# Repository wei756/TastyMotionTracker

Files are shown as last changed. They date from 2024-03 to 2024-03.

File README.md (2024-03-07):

# TastyMotionTracker
TastyMotionTracker-SlimeVR PCB SMT Project

- Very tiny size
- Using BMI160 6-DoF IMU
- I2C port for additional IMU
- CH340E UART-USB Interface
- Charging Li-Po Battery support

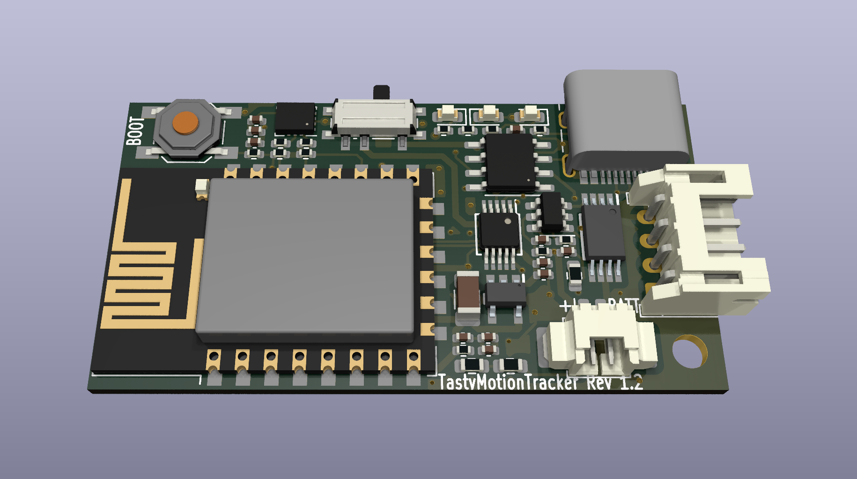
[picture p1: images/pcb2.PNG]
pcb1

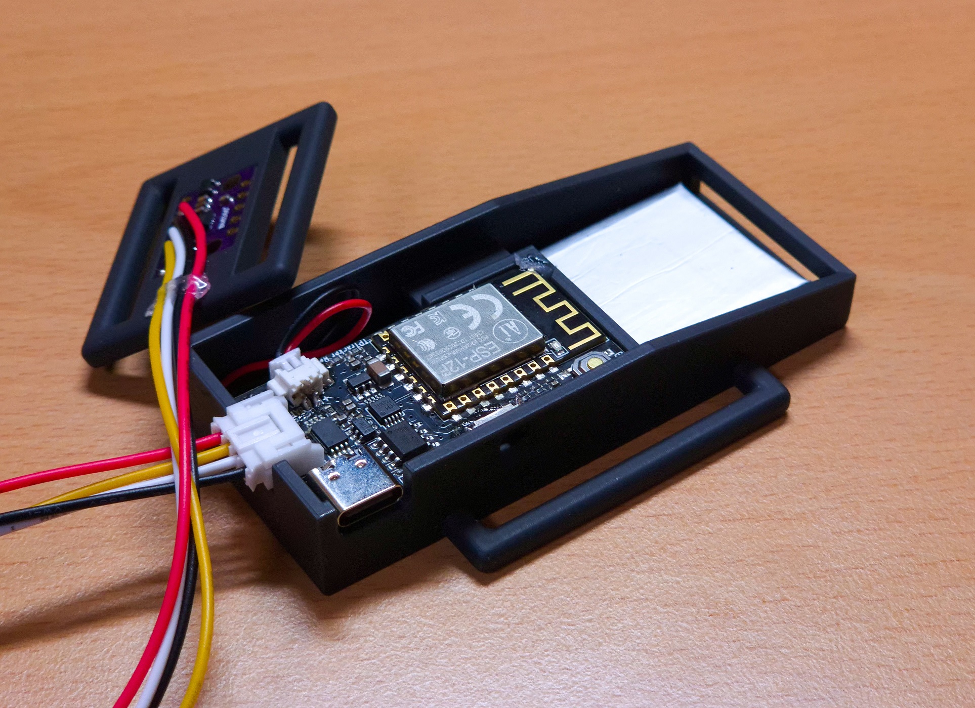
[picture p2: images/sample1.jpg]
sample1


## License
**This hardware is licensed under the CERN-OHL-P v2 license**, which is a permissive,
non-viral and non-reciprocal open hardware license. Unlike software licenses like
MIT and Apache 2.0, it better handles the nuances of hardware and protects both
the licensor and licensee from patent lawsuits.

**Unless you explicitly state otherwise, any contribution intentionally submitted
for inclusion in this work by you, shall be licensed as above, without any
additional terms or conditions.**

### Conveying notice of License
Note that as part of the CERN-OHL-P v2 license, recipients of manufactured
hardware must also receive notice of the above license. One such
method of conveying the notice is to include a link to the original source repo,
or printing "Licensed under CERN-OHL-P v2" on the PCB silkscreen. For more info,
see [here](https://ohwr.org/project/cernohl/wikis/Documents/CERN-OHL-version-2).

This is conceptually similar to the MIT/Apache 2.0 Licenses, where the original
license must still be included as a notice even when the source is modified and
subsequently relicensed under different terms.

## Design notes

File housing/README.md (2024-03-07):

# TastyMotionTracker-Housing

- Using 3.8x27x74mm 800mAh Li-Po Battery

### TODO
- add a cover
- change battery

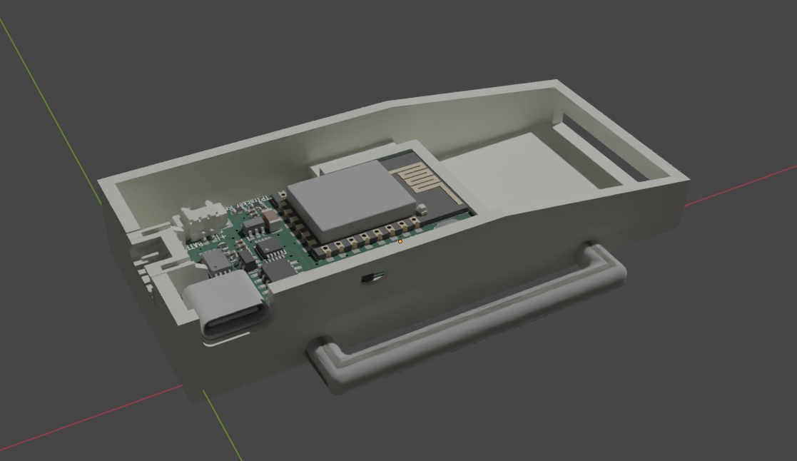
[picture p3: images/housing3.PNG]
housing3

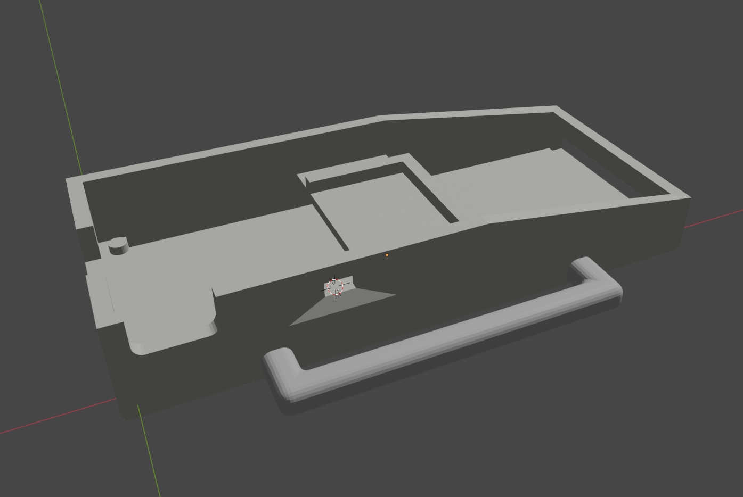
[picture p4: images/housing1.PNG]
housing1

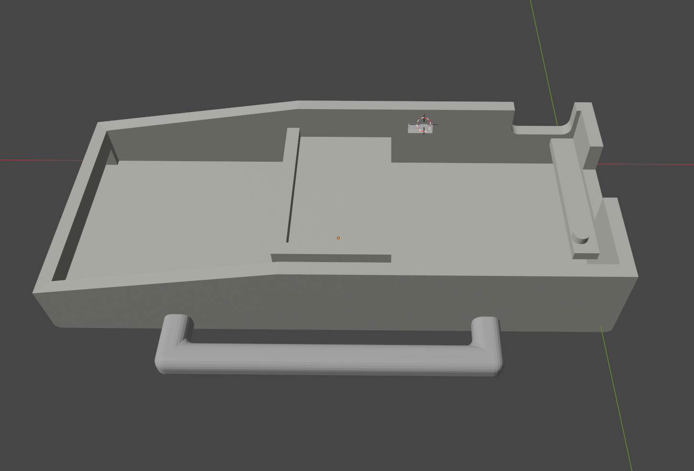
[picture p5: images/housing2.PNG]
housing2


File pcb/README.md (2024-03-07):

# TastyMotionTracker-PCB

### TODO
- fix battery indicator.

pcb2
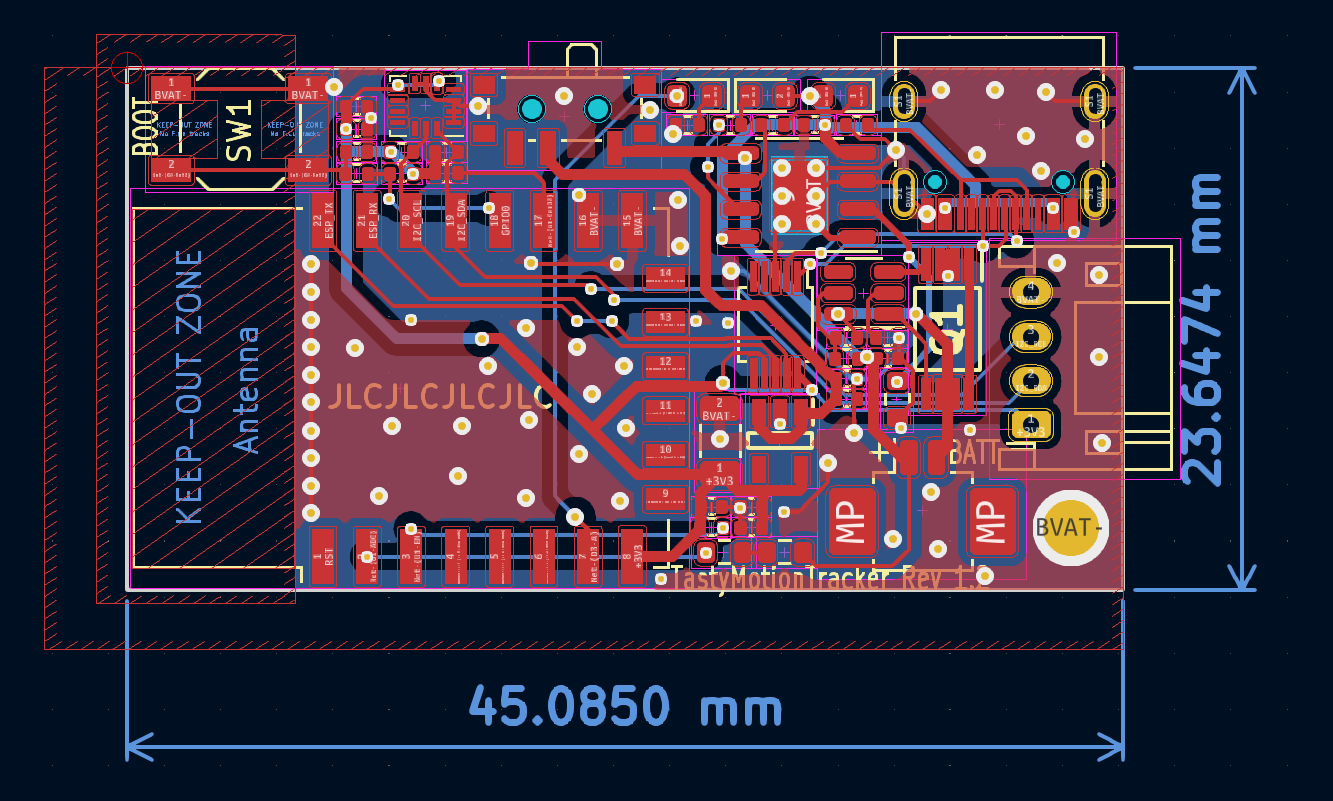
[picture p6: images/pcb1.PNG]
pcb1

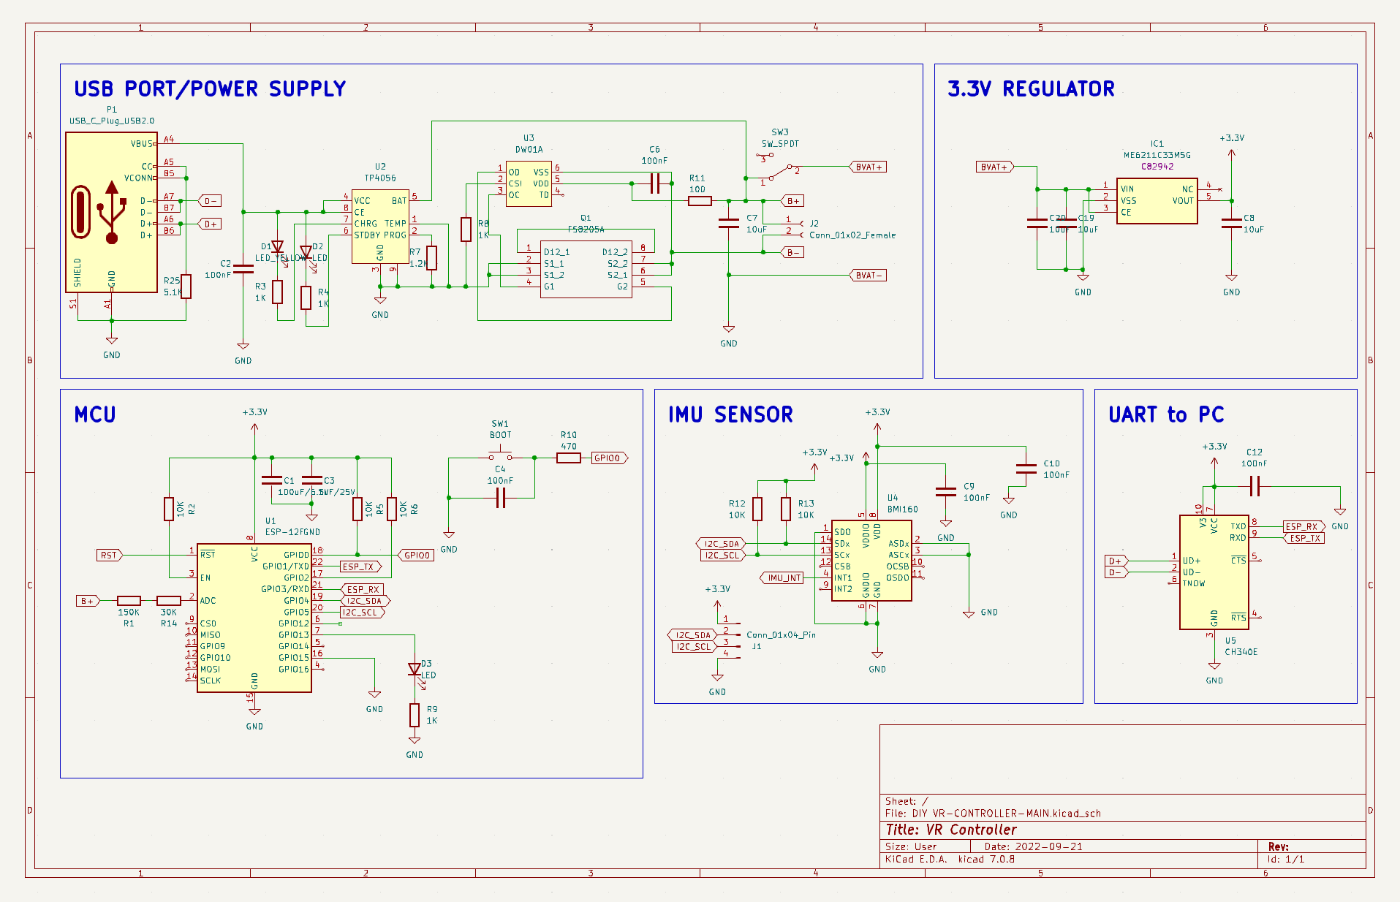
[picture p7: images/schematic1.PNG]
schematic1


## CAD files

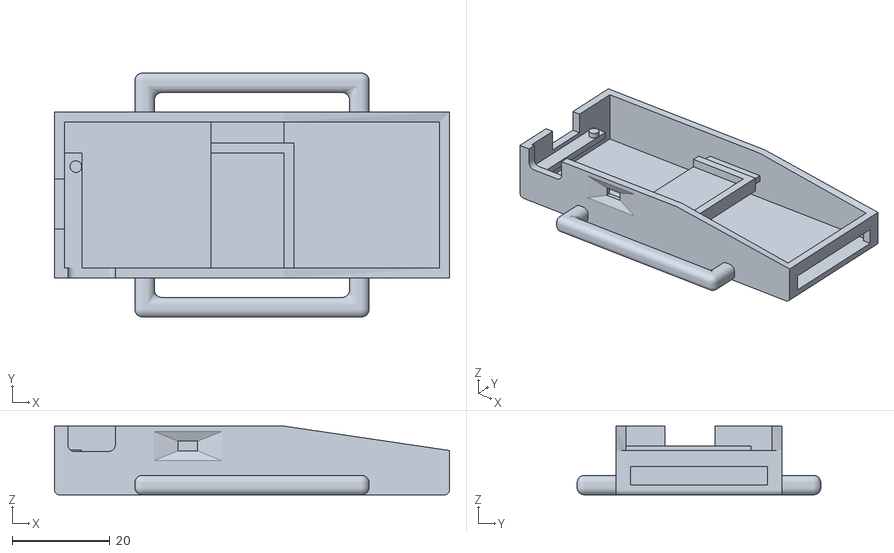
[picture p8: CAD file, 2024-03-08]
housing/TMTracker housing v1.1.stl
81.0 x 50.0 x 14.1

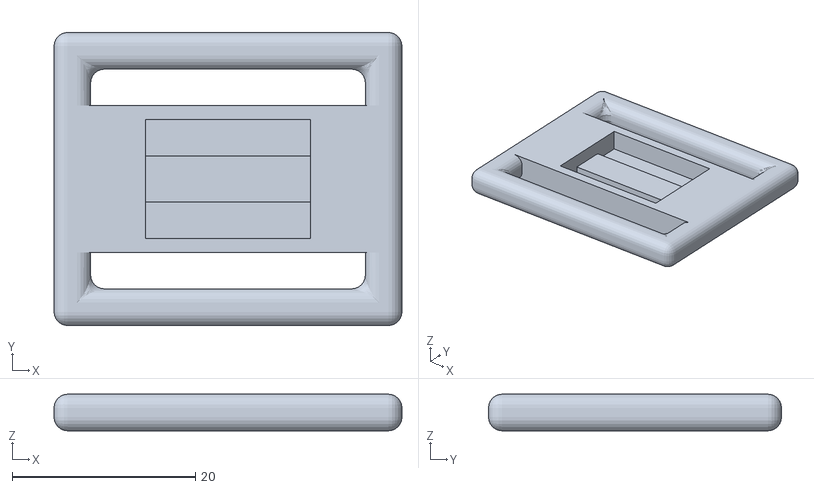
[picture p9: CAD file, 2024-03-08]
housing/TMTracker_ext housing v1.1.stl
38.0 x 32.0 x 4.00

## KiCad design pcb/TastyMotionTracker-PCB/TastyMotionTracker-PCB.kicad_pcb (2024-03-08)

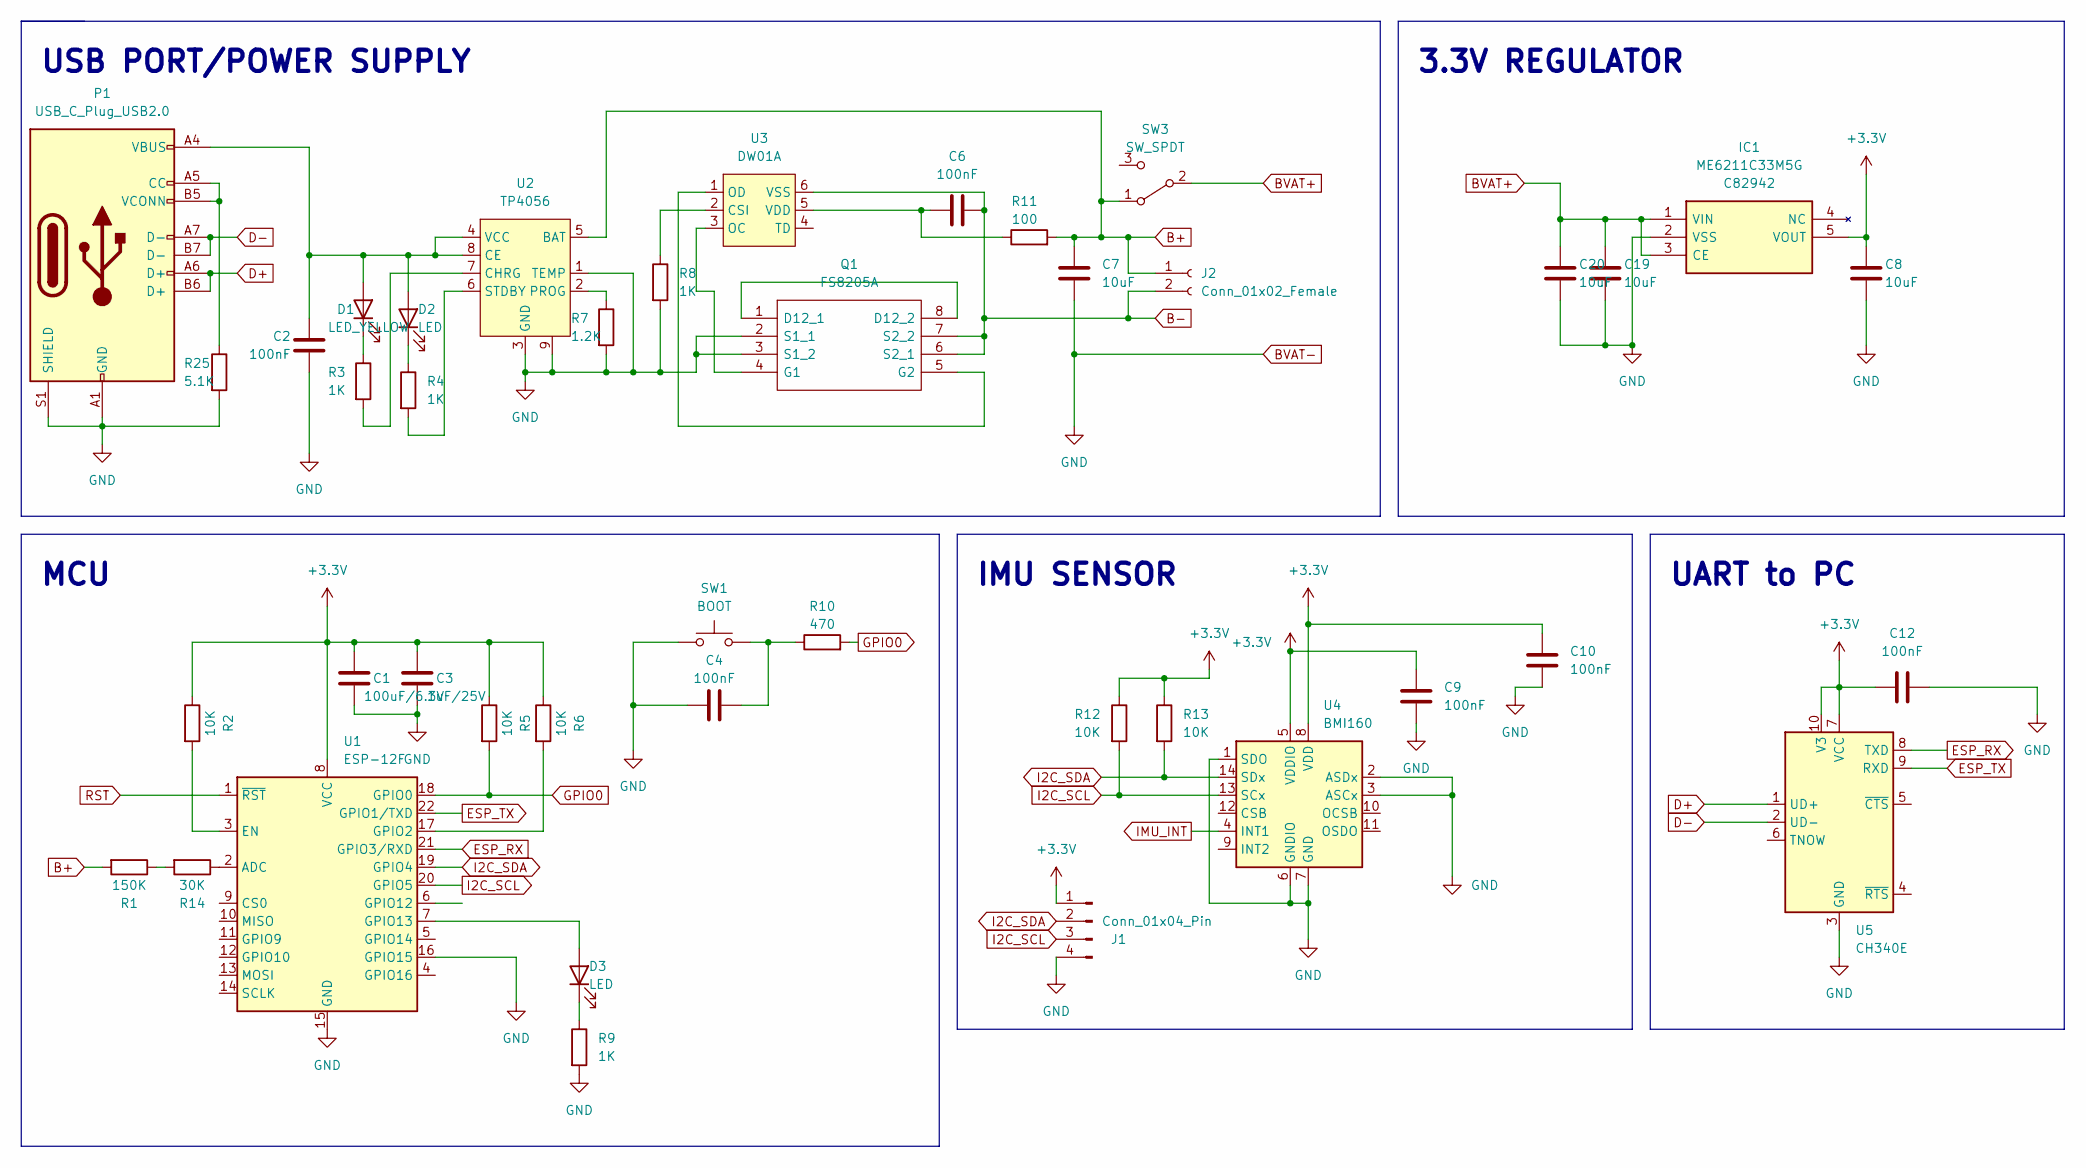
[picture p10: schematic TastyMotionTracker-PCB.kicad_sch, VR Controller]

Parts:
C1: 100uF/6.3V; C_1206_3216Metric; LCSC C15008
C2, C4, C6, C9, C10, C12: 100nF; C_0402_1005Metric; LCSC C1525
C3: 1uF/25V; C_0402_1005Metric; LCSC C52923
C7, C8, C19, C20: 10uF; C_0402_1005Metric; LCSC C15525
D1: LED_YELLOW; LED_0603_1608Metric; LCSC C72038
D2, D3: LED; LED_0603_1608Metric; LCSC C72041
IC1: ME6211C33M5G; SOT95P282X145-5N; Manufacturer_Part_Number ME6211C33M5G; LCSC C82942
J1: Conn_01x04_Pin; JST_PH_S4B-PH-K_1x04_P2.00mm_Horizontal; LCSC C157926
J2: Conn_01x02_Female; Molex_PicoBlade_53261-0271_1x02-1MP_P1.25mm_Horizontal; LCSC C189700
P1: USB_C_Plug_USB2.0; USB_C_Receptacle_HRO_TYPE-C-31-M-12; LCSC C167321
Q1: FS8205A; SOP65P640X120-8N; Manufacturer_Part_Number FS8205A; LCSC C16052
R1: 150K; R_0603_1608Metric; LCSC C22807
R2, R5, R6, R12, R13: 10K; R_0402_1005Metric; LCSC C25744
R3, R4, R8, R9: 1K; R_0402_1005Metric; LCSC C11702
R7: 1.2K; R_0603_1608Metric; LCSC C22765
R10: 470; R_0402_1005Metric; LCSC C25117
R11: 100; R_0402_1005Metric; LCSC C25076
R14: 30K; R_0603_1608Metric; LCSC C22984
R25: 5.1K; R_0402_1005Metric; LCSC C25905
SW1: BOOT; SW_SPST_SKQG_WithoutStem; LCSC C318884
SW3: SW_SPDT; SW_SPDT_PCM12; LCSC C319019
U1: ESP-12F; ESP-12E; LCSC C82891
U2: TP4056; HSOP-8-1EP_3.9x4.9mm_P1.27mm_EP2.41x3.1mm; LCSC C16581
U3: DW01A; SOT-23-6; LCSC C61503
U4: BMI160; Bosch_LGA-14_3x2.5mm_P0.5mm; LCSC C94021
U5: CH340E; MSOP-10_3x3mm_P0.5mm; LCSC C99652

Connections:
+3V3: C1.1, C3.1, C8.1, C9.1, C10.1, C12.1, IC1.5 (VOUT), J1.1, R2.1, R5.1, R6.1, R12.1, R13.1, U1.8 (VCC), U4.5 (VDDIO), U4.8 (VDD), U5.7 (VCC), U5.10 (V3)
B+: C7.1, J2.1, R1.2, R11.2, SW3.1 (A), U2.5 (BAT)
B-: C6.2, J2.2, Q1.6 (S2_1), Q1.7 (S2_2), U3.6 (VSS)
BVAT+: C19.1, C20.1, IC1.1 (VIN), IC1.3 (CE), SW3.2 (B)
BVAT-: C1.2, C2.2, C3.2, C4.1, C7.2, C8.2, C9.2, C10.2, C12.2, C19.2, C20.2, IC1.2 (VSS), J1.4, P1.A1 (GND), P1.A12 (GND), P1.B1 (GND), P1.B12 (GND), P1.S1 (SHIELD), Q1.2 (S1_1), Q1.3 (S1_2), R7.2, R8.2, R9.2, R25.2, SW1.1, U1.15 (GND), U1.16 (GPIO15), U2.1 (TEMP), U2.3 (GND), U2.9, U4.1 (SDO), U4.2 (ASDx), U4.3 (ASCx), U4.6 (GNDIO), U4.7 (GND), U5.3 (GND)
D+: P1.A6 (D+), P1.B6 (D+), U5.1 (UD+)
D-: P1.A7 (D-), P1.B7 (D-), U5.2 (UD-)
ESP_RX: U1.21 (GPIO3/RXD), U5.8 (TXD)
ESP_TX: U1.22 (GPIO1/TXD), U5.9 (RXD)
GPIO0: R5.2, R10.2, U1.18 (GPIO0)
I2C_SCL: J1.3, R12.2, U1.20 (GPIO5), U4.13 (SCx)
I2C_SDA: J1.2, R13.2, U1.19 (GPIO4), U4.14 (SDx)
IMU_INT: U4.4 (INT1)
unnamed: C4.2, R10.1, SW1.2
unnamed: C2.1, D1.2 (A), D2.2 (A), P1.A4 (VBUS), P1.A9 (VBUS), P1.B4 (VBUS), P1.B9 (VBUS), U2.4 (VCC), U2.8 (CE)
unnamed: D1.1 (K), R3.1
unnamed: D2.1 (K), R4.1
unnamed: D3.2 (A), U1.7 (GPIO13)
unnamed: D3.1 (K), R9.1
unnamed: P1.A5 (CC), P1.B5 (VCONN), R25.1
unnamed: Q1.1 (D12_1), Q1.8 (D12_2)
unnamed: Q1.4 (G1), U3.3 (OC)
unnamed: Q1.5 (G2), U3.1 (OD)
unnamed: R1.1, R14.2
unnamed: R14.1, U1.2 (ADC)
unnamed: R2.2, U1.3 (EN)
unnamed: R6.2, U1.17 (GPIO2)
unnamed: R3.2, U2.7 (CHRG)
unnamed: R7.1, U2.2 (PROG)
unnamed: R4.2, U2.6 (STDBY)
unnamed: R8.1, U3.2 (CSI)
unnamed: C6.1, R11.1, U3.5 (VDD)
RST: U1.1 (~RST)

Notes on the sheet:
USB PORT/POWER SUPPLY
MCU
IMU SENSOR
3.3V REGULATOR
UART to PC

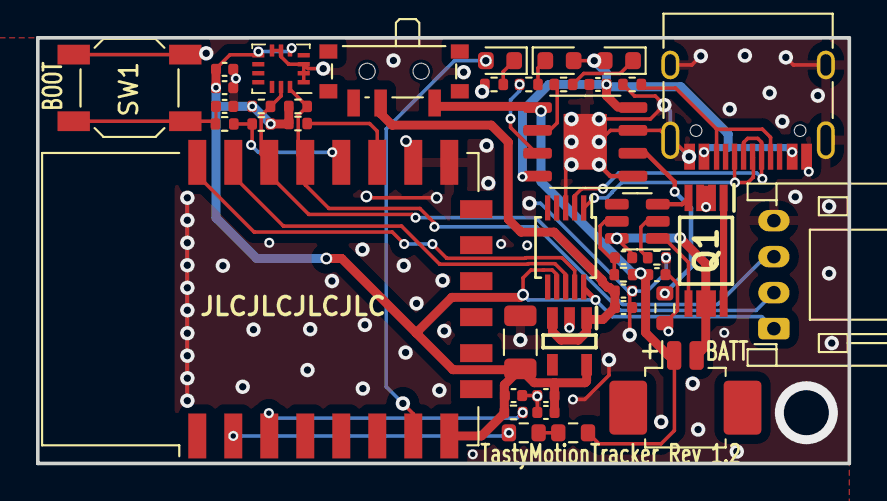
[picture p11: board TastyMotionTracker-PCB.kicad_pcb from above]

Board: 2 copper layers, 45.1 x 23.6 mm, 42 parts (0 on the bottom side), 31 nets.

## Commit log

2024-03-08 upload pcb project
    [TastyMotionTracker-PCB.kicad_pcb, TastyMotionTracker-PCB.kicad_sch]
2024-03-08 upload 3d printing models
    [TMTracker housing v1.1.stl, TMTracker_ext housing v1.1.stl]
